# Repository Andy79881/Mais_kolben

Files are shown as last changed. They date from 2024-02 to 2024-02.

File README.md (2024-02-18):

# Soldering-station
### ***based on Weller RT soldering tip***

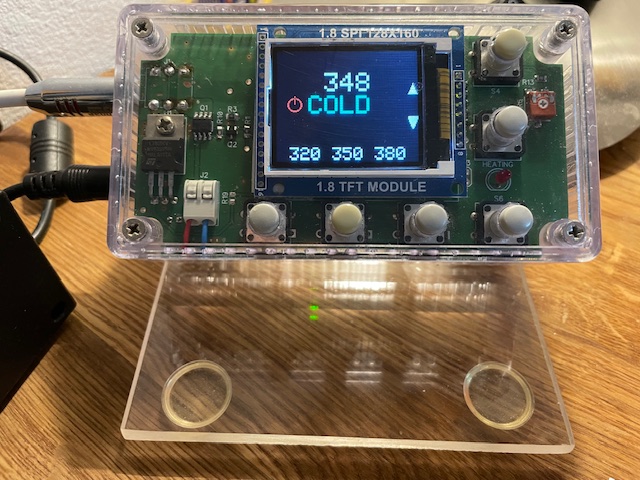
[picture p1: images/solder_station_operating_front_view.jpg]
Soldering station after power-up Soldering station in operation - after power-up


History
----

 This soldering station is my own build version of the station shown in [Heise Make 05/2016](https://www.heise.de/select/make/2016/5/1476695937422186). I made this already in 2017 but never documented it. Now, during process of software update I thought it would be a good idea to document this project and make it available for the public. 
 Credits for original design goes to Luca Zimmermann.
 Original code is hosted here: [ArduinoHannover/Maiskolben](https://github.com/ArduinoHannover/Maiskolben). I have not forked the code from Luca in order to avoid doubling the information and wasting memory. 
 In order to make this customized build there is no need to have the original code. Nevertheless, you will find all informations regarding code history, features of the different versions as well as the user manual in the repository, which hosts the original code.
 
 I have created my own custom PCB, which is build into a standard housing from Hammond (type 1591C), so no need to make 3D Prints.
 The hardware is based on the original design. However the key layout has been adopted to my needs. The software (source code) can be found in an own repository:
 [soldering_station_software](https://github.com/Andy79881/soldering_station_software). Unfortunately I could not manage to integrate the software repository into this one.

Below you find the changes to the original design from [ArduinoHannover/Maiskolben](https://github.com/ArduinoHannover/Maiskolben)

Code Baseline:
---
- Refer to Readme of [soldering_station_software](https://github.com/Andy79881/soldering_station_software).

Changes to original HW design and code:
----

- Backlight can be adjusted via potentiometer (no PWM controlled TFT brightness)
- customized PCB to fit into standard housing from Hammond (type 1591C)
- Code changes are described in Readme of [soldering_station_software](https://github.com/Andy79881/soldering_station_software)

HW Design decisions:
----
- Diptrace is used for schematics and PCB layout creation (note: free editition 4.x can be used)
- almost SMD components used (except 5V regulator, connectors, push buttons, LED and Arduino Nano)

Construction and assembly notes:
---
- two copper-clad PCBs are inserted vertically into Hammond enclosure as spacers to keep distance of PCB to the lid - see figure below:

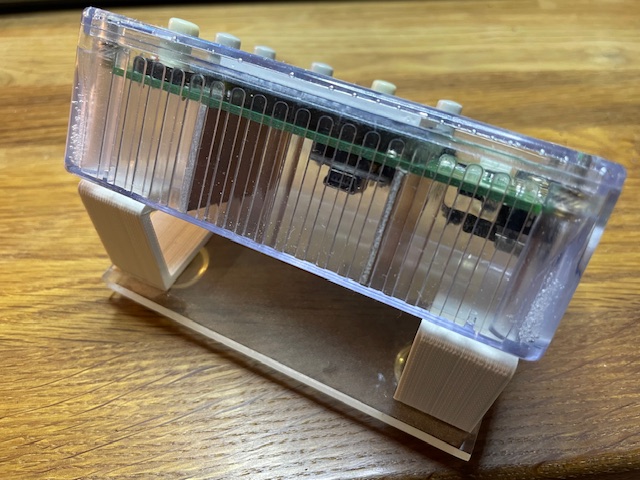
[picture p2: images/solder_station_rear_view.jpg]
Soldering station rear view Soldering station rear view - showing PCBs as spacers


- holes are drilled into the lid for the tactile caps of the push buttons.
- no cut-out for display needed
- enclosure mounted with two 3D printed angle brackets to a base plate

Final Remarks:
---
- feel free to build your own soldering station and stay creative
- HW design data is provided **AS IS**, so no warranties.

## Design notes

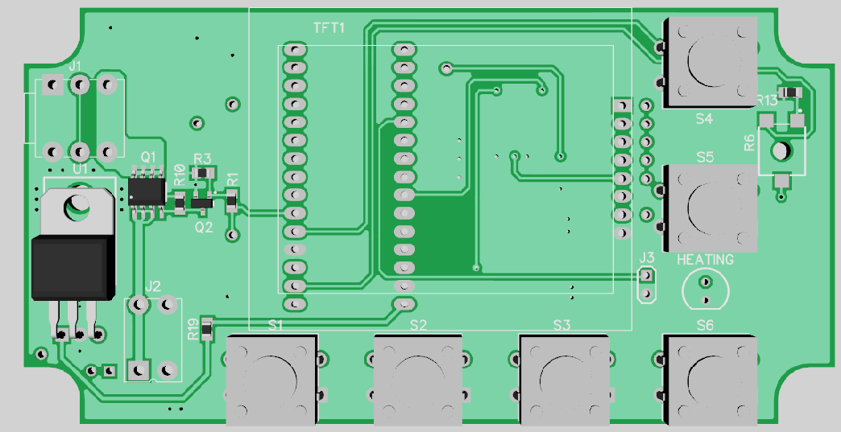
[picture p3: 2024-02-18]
Diptrace/Dokumentation/PCB_3D_top.png

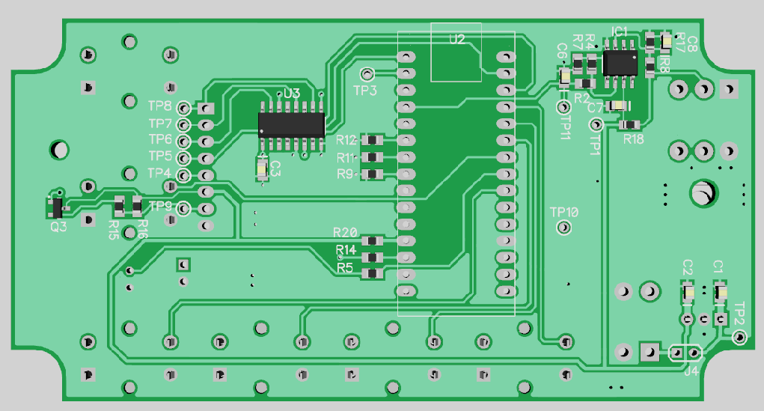
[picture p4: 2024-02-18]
Diptrace/Dokumentation/PCB_3D_bottom.png

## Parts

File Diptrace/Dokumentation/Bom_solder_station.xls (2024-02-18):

RefDes | Value | Name
C1 | 100nF | CAP_0805
C2 | 100nF | CAP_0805
C3 | 100nF | CAP_0805
C6 | 10nF | CAP_0805
C7 | 100nF | CAP_0805
C8 | 10nF | CAP_0805
HEATING | RED | LED5MM
IC1 | OPA703PA | OPA340P
J1 |  | FCR1295
J2 |  | WAGO2600-1402
J3 |  | JUMPER_2
J4 |  | JUMPER_2
Q1 | IRF5305 | IRF7416
Q2 | 2N7000 | 2N7002
Q3 |  | 2N7002
R1 | 1k | RES_0805
R2 | 5K6 | RES_0805
R3 | 10k | RES_0805
R4 | 68K | RES_0805
R5 | 220R | RES_0805
R6 | 10k | ACP6
R7 | 100R | RES_0805
R8 | 5K6 | RES_0805
R9 | 10k | RES_0805
R10 | 10k | RES_0805
R11 | 10k | RES_0805
R12 | 10k | RES_0805
R13 | 100k | RES_0805
R14 | 0R | RES_0805
R15 | 0R | RES_0805
R16 | 22R | RES_0805
R17 | 100k | RES_0805
R18 | 10M | RES_0805
R19 | 0R | RES_0805
R20 | 0R | RES_0805
S1 |  | B3F-4050
S2 |  | B3F-4050
S3 |  | B3F-4050
S4 |  | B3F-4050
S5 |  | B3F-4050
S6 |  | B3F-4050
TFT1 | 1.8TFT_BLUE | 1.8TFT_BLUE
TP1 |  | TESTPOINT
TP2 |  | TESTPOINT
TP3 |  | TESTPOINT
TP4 |  | TESTPOINT
TP5 |  | TESTPOINT
TP6 |  | TESTPOINT
TP7 |  | TESTPOINT
TP8 |  | TESTPOINT
TP9 |  | TESTPOINT
TP10 |  | TESTPOINT
TP11 |  | TESTPOINT
U1 |  | 7805
U2 | ARDUINO_NANOR3 | ARDUINO_NANOR3
U3 |  | M74HC4050M1R

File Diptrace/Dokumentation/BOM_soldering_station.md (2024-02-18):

| #  | RefDes | Quantity | Value | Pattern | Manufacturer |
|----|---|---|---|---|---|
| 1  | C1, C2, C3, C7 | 4 | 100nF | CAP_0805 | |
| 2  | C6, C8 | 2 | 10nF | CAP_0805 | |
| 3  | HEATING | 1 | RED | LED5MM | |
| 4  | IC1 | 1 | OPA340P | SOIC-8/150mil  | TI |
| 5  | J1 | 1 | FCR1295 | FCR1295 | Cliff |
| 6  | J2 | 1 | WAGO2600-1402  | WAGO2060-1402  | WAGO |
| 7  | J3, J4 | 2 | JUMPER_2 | JMP2 | |
| 8  | Q1 | 1 | IRF7416 | SOIC-8/150mil  | IR |
| 9  | Q2 | 1 | 2N7002 | SOT23 | Philips-NXP |
| 10 | Q3 | 1 | 2N7002 | SOT23 | Philips-NXP |
| 11 | R1 | 1 | 1k | RES_0805 | |
| 12 | R2, R8 | 2 | 5K6 | RES_0805 | |
| 13 | R3, R9, R10, R11, R12  | 5 | 10k | RES_0805 | |
| 14 | R4 | 1 | 68K | RES_0805 | |
| 15 | R5 | 1 | 220R | RES_0805 | |
| 16 | R6 | 1 | 10k | ACP6 | Copal Electronics |
| 17 | R7 | 1 | 100R | RES_0805 | |
| 18 | R13, R17 | 2 | 100k | RES_0805 | |
| 19 | R14, R15, R19, R20 | 4 | 0R | RES_0805 | |
| 20 | R16 | 1 | 22R | RES_0805 | |
| 21 | R18 | 1 | 10M | RES_0805 | |
| 22 | S1, S2, S3, S4, S5, S6 | 6 | B3F-4050 | B3F-5 | OMRON |
| 23 | TFT1 | 1 | 1.8TFT_BLUE | 1.8TFT_BLUE | |
| 24 | U1 | 1 | uA7805 | TO-220H | |
| 25 | U2 | 1 | ARDUINO_NANOR3 | ARDUINO-NANO | |
| 26 | U3 | 1 | M74HC4050M1R | SOIC-16/150mil | ST Microelectronics |

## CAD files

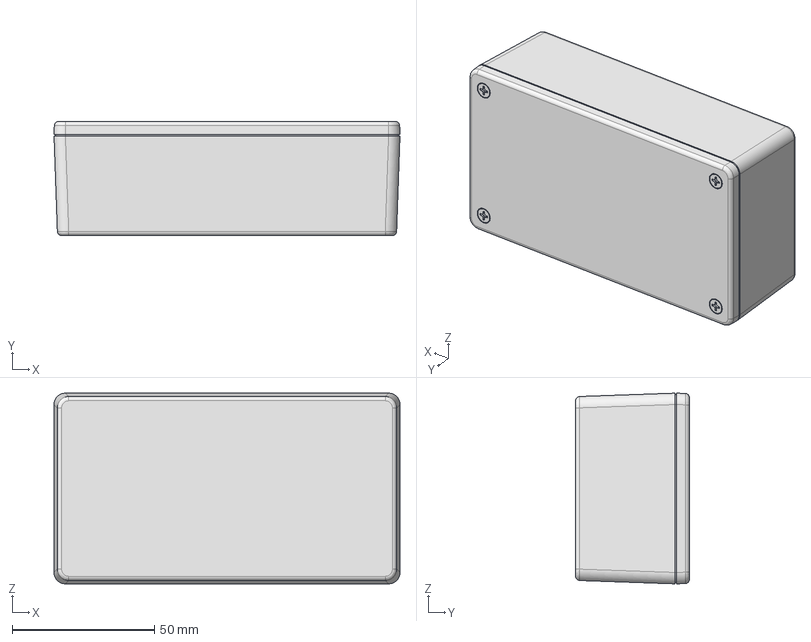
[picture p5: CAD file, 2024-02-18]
Diptrace/_datasheets/Enclosure_Hammond/1591XXC.stp
121.4 x 40.0 x 66.9 mm
1591XXC BOX
1591XXC LID
SC500 (screw M3-0.5X 10mm FH) x 4
IN100 (insert M3-0.5X5.75mm BRASS) x 4

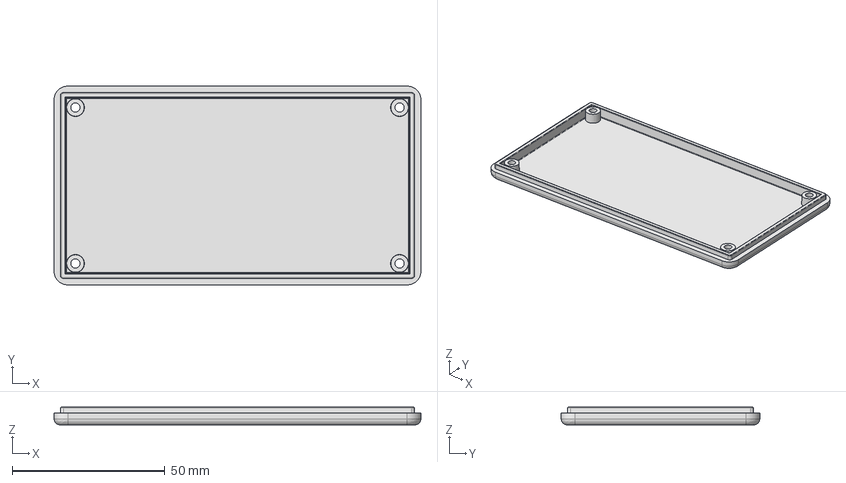
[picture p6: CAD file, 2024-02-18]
Diptrace/_datasheets/Enclosure_Hammond/485528-da-01-en-3D_CAD/1591C Lid.stp
120.0 x 65.0 x 5.80 mm

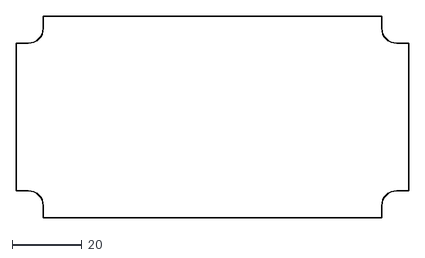
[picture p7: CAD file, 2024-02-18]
Diptrace/PCB_outline.dxf
113.0 x 58.0

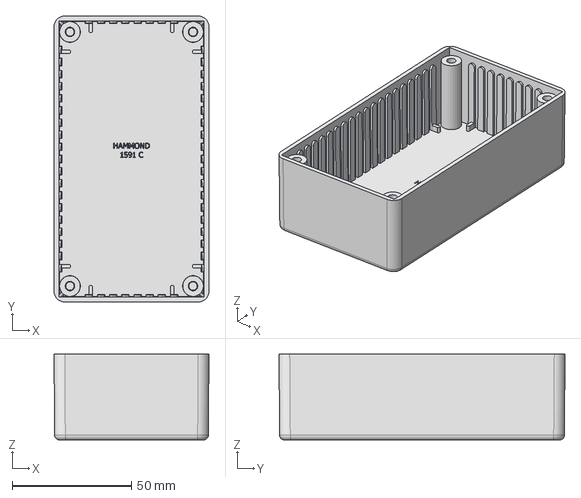
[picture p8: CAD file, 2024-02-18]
Diptrace/_datasheets/Enclosure_Hammond/485528-da-01-en-3D_CAD/1591C Box.stp
65.0 x 120.0 x 36.0 mm

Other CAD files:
Diptrace/_datasheets/Enclosure_Hammond/1591XXC.dwg
Diptrace/_datasheets/Enclosure_Hammond/1591XXC.igs
Diptrace/_datasheets/Enclosure_Hammond/485528-da-01-en-3D_CAD/1591C Box.igs
Diptrace/_datasheets/Enclosure_Hammond/485528-da-01-en-3D_CAD/1591C Lid.igs
Diptrace/_datasheets/Enclosure_Hammond/solderstation_pult.skp

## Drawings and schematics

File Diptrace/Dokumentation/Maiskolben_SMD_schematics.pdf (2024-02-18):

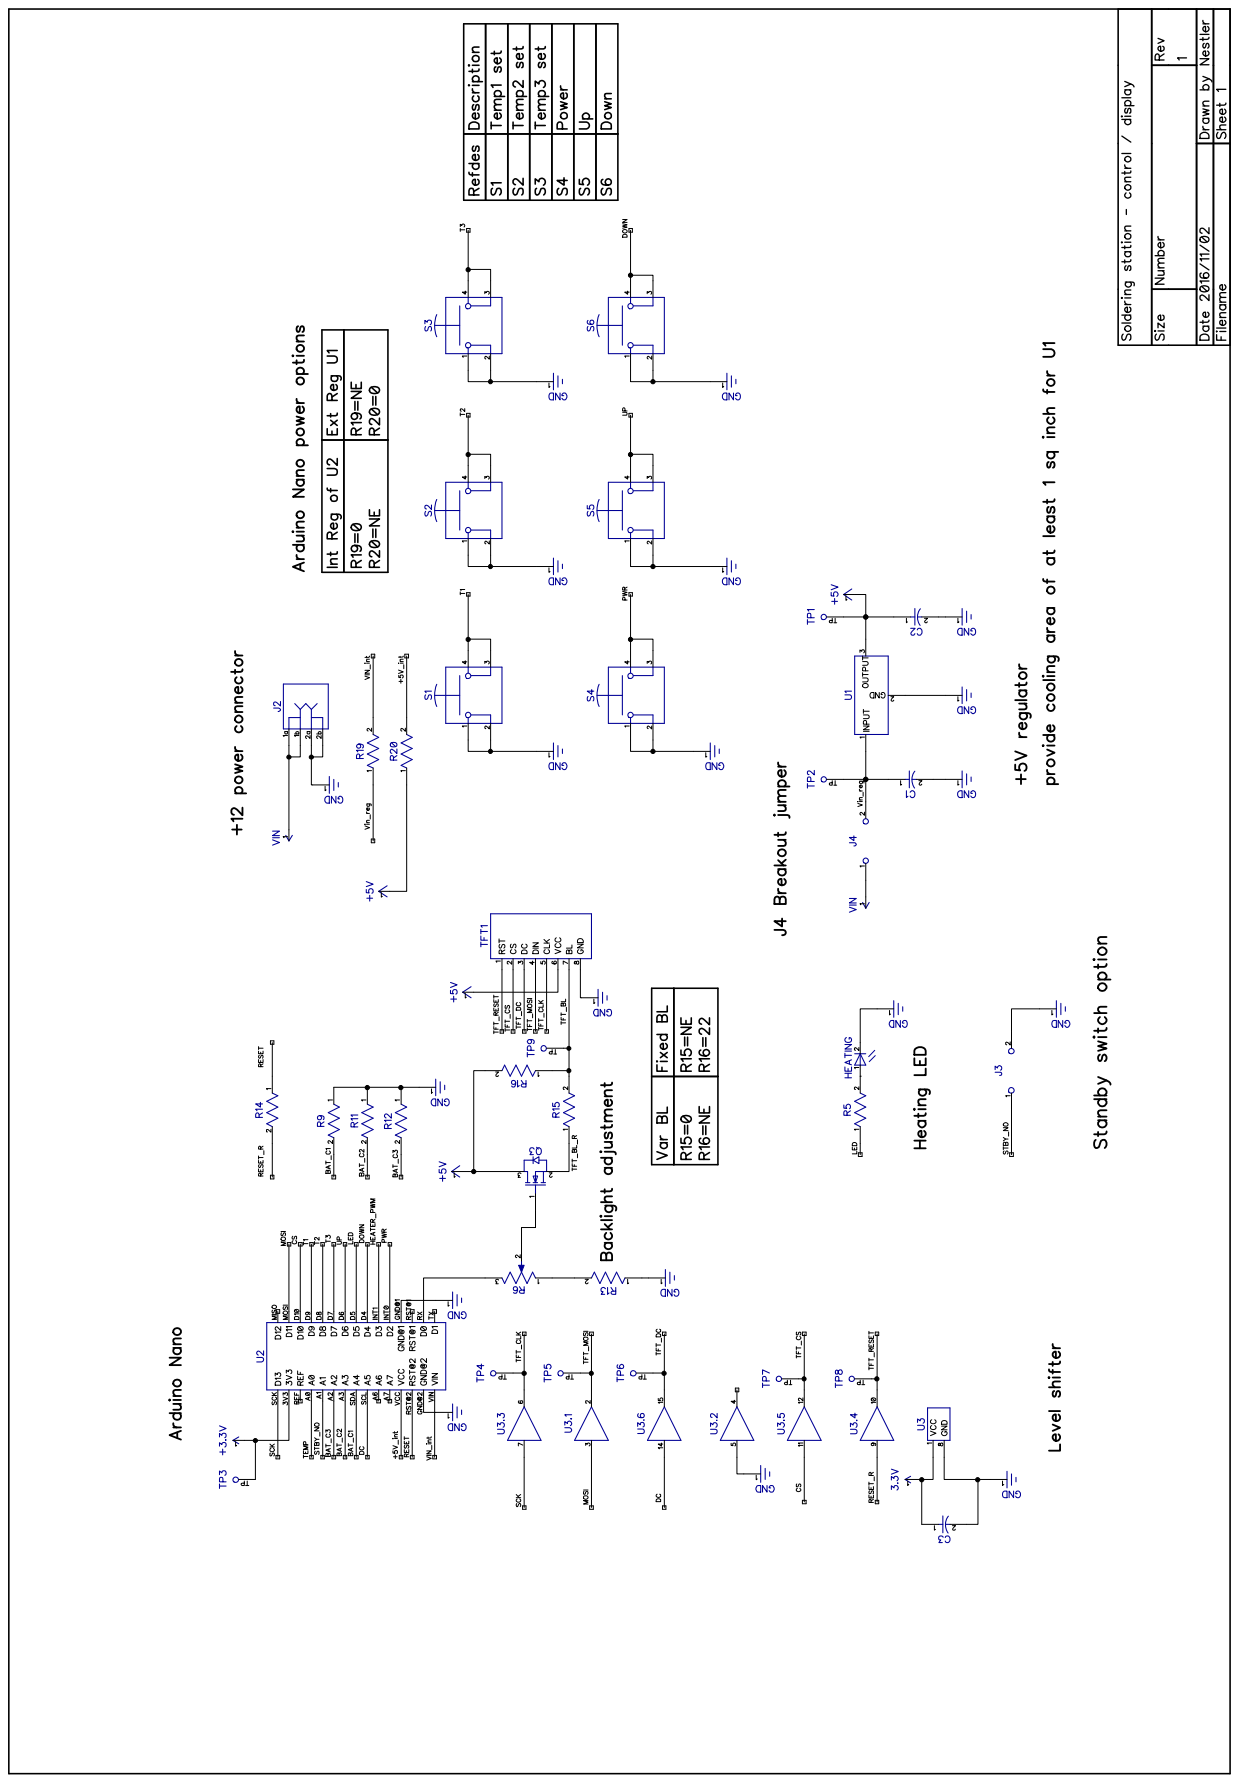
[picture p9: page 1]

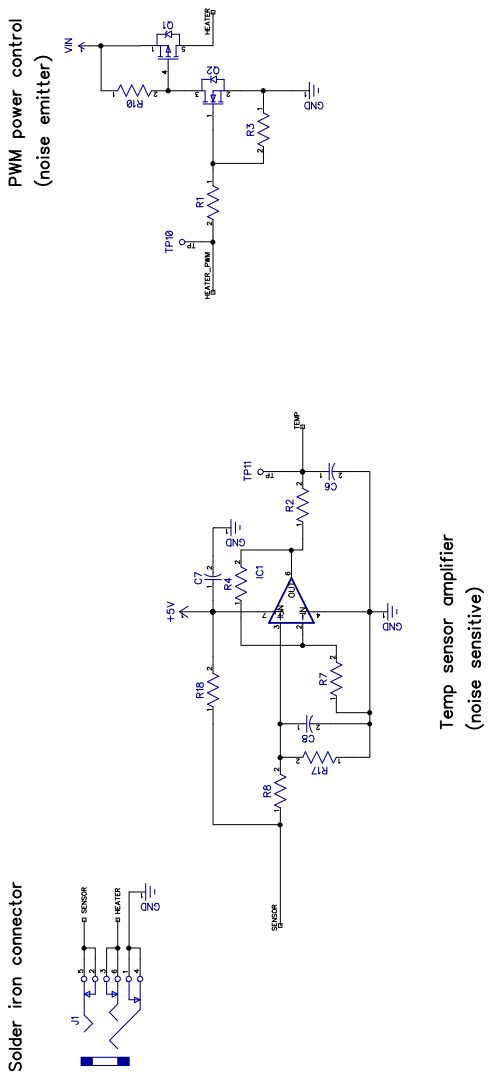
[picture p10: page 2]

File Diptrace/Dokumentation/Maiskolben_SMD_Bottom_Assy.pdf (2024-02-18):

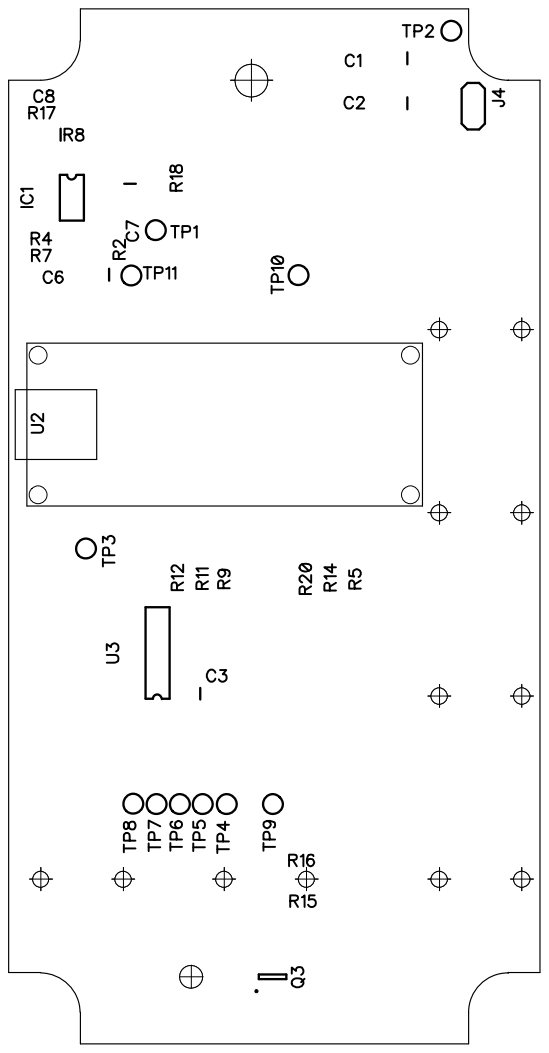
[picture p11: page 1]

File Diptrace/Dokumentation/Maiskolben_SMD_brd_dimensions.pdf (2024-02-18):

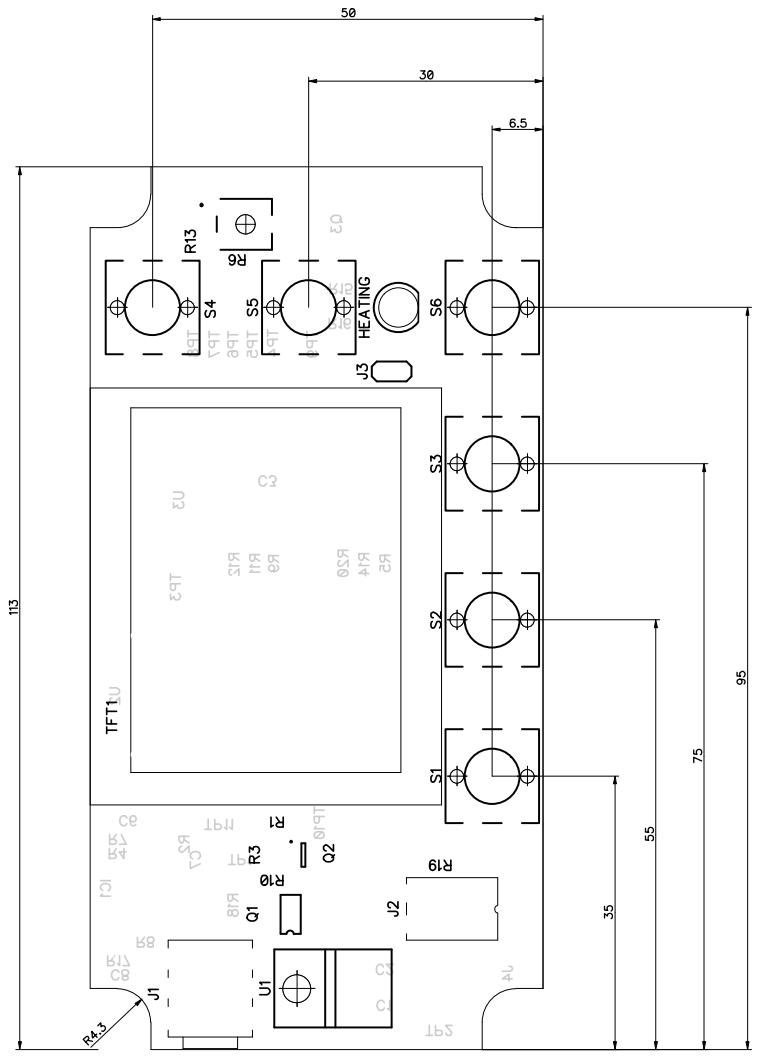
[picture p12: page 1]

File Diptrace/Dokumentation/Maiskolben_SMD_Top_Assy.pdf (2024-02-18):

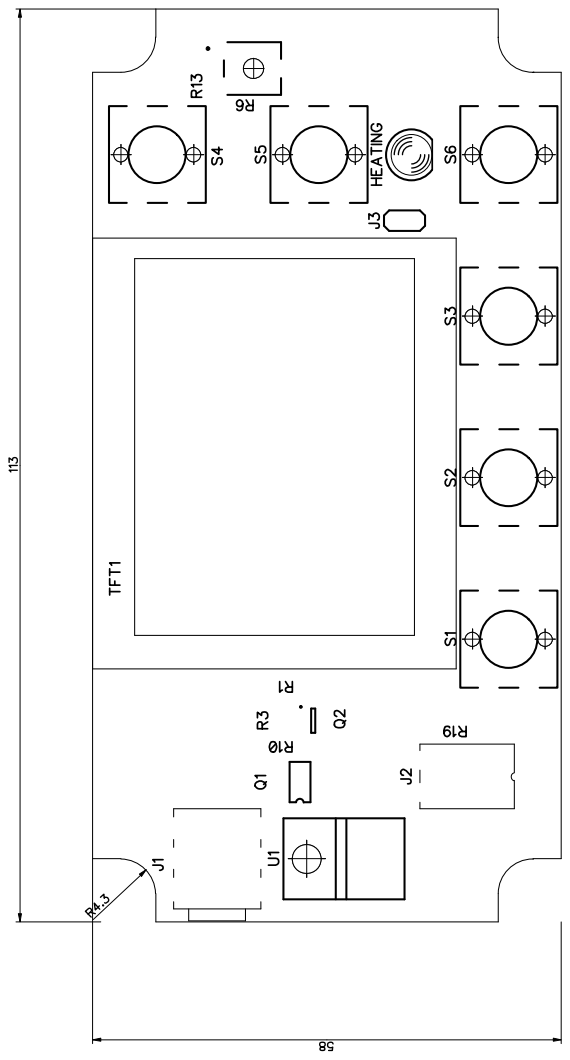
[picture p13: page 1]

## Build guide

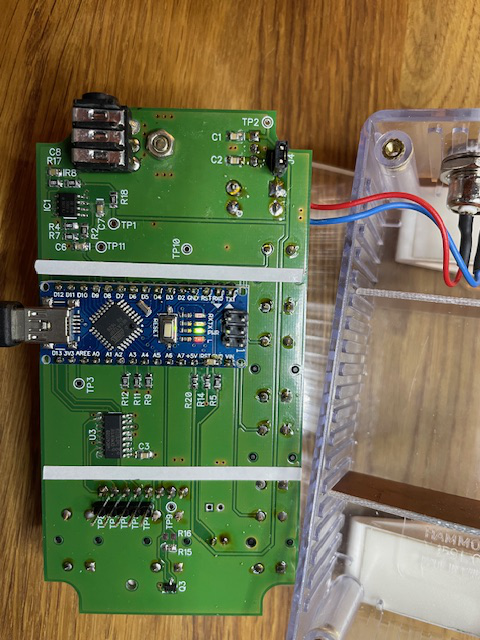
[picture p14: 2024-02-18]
images/solder_station_Arduino_prog_2.jpg

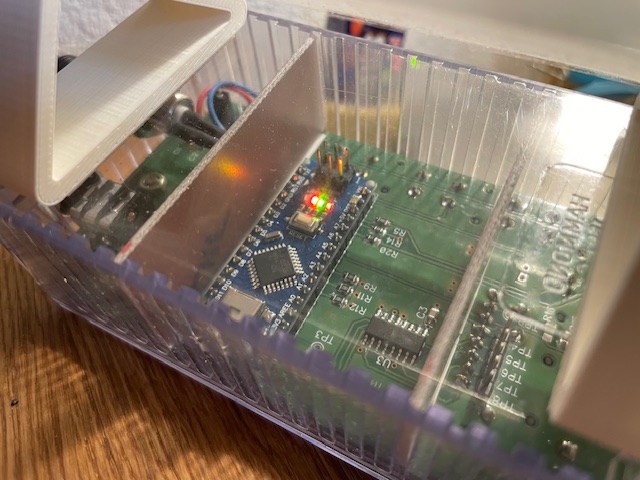
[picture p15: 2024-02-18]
images/solder_station_bottom_view.jpg

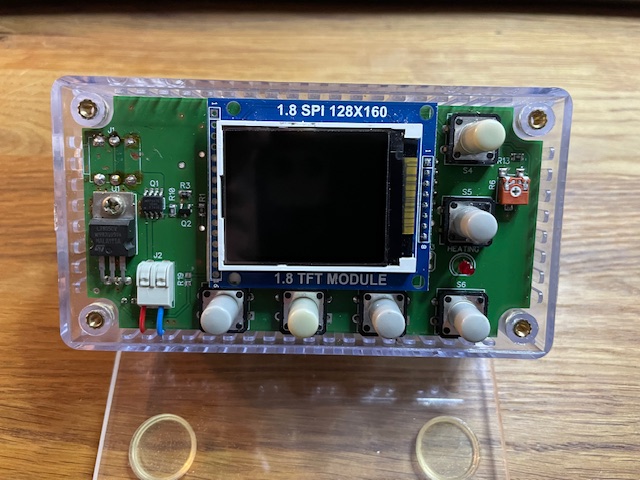
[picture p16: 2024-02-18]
images/solder_station_no_cover_front_view.jpg
